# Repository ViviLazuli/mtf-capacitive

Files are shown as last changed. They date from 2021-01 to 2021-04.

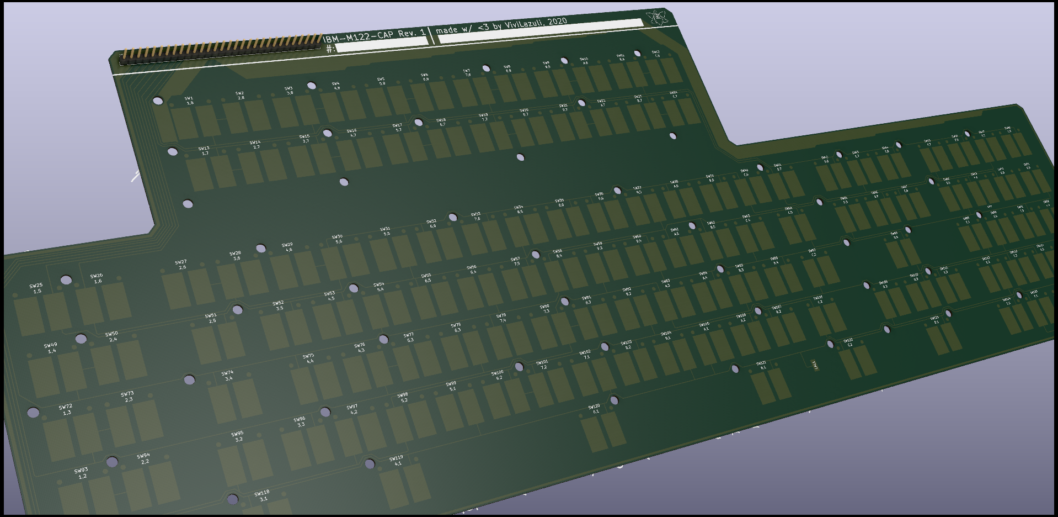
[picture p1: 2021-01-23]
docs/render-front.png

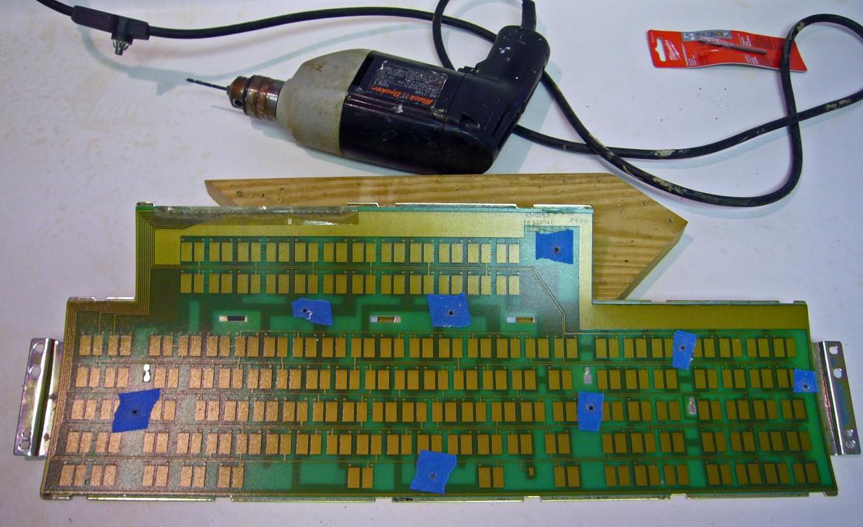
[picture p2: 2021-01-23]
docs/reverse-engineering/2.png

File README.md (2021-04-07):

# MtF122 Capacitive Conversion PCB for IBM Model M 122-key Keyboards

### Rev. 2 / Rev. B

This version is in prototyping phase. However, it does function.

It has only been tested with a late thin-bezeled variant of the M122. The screw holes have a tight fit and may require widening and more clearance around them for traces.
!The screw holes may not be in the correct positions for other M122 variants!

Capacitive pad measurements are taken from i$/idollar's FSSK and FEXT PCB designs, which I believe are directly measured from the original Model F PCBs.

The PCB thickness should be 0.6mm. This is thin enough to allow the board to flex into shape without preforming it with heat and duct tape (which I couldn't make work anyway).

Standard glossy soldermask is probably the best choice. JLCPCB has had issues with wear on their black soldermask before. They have changed the formula, but a standard green/red/blue/yellow/purple/white/etc. glossy solder mask is probaby the safest bet for keyswitch wear resistance.
Higher wear resistance might also be achieved by coating the front of the capacitive pads in silkscreen, as silkscreen is an extra layer of epoxy. I am unsure how this will affect keyfeel or actuation, however.

There is a bullseye circle on the front of the board. This is for drilling a hole for a trackpoint module. There are redundant traces to allow for safer drilling at this location, but this functionality has not been tested!

The diameter of the copper around the connecting pads could be to be enlarged. They are too fragile and I had one rip out when disconnecting a mill-max pin header connector (fortunately it was just a redundant ground).

For connecting the board to an xwhatsit or other controller, I would recommend 3M 8132/06 100, which has the correct pitch for this board and xwhatsit:
https://www.digikey.com/en/products/detail/3m/8132-06-100/7809902

The key matrix of the PCB is reverse-engineered from photos of original F122 PCBs and should be exactly the same. The connector is likely in a slightly different position though.

The screw hole placement was prototyped with paper by printing an SVG output of the board edge cuts and drill holes on multiple sheets of paper, pasting them together, cutting out the paper 'PCB', and hole punching the drill hole locations. A few iterations of this paper prototyping method allowed me to test hole locations and board fitment against the barrel plate without having to make an entire PCB first.

I did not clad the steel backplate in tape before mounting the PCB. The solder mask should provide adequate isolation. Just make sure the steel is clean and there are no burrs/jagged edges that could scrape the PCB.

Please read LICENSE.txt for the full MIT License.

Some photos are here for reverse-engineering reference only and are not mine nor included under the license.

| Authors |
|-|
| ViviLazuli |
| Razerban |

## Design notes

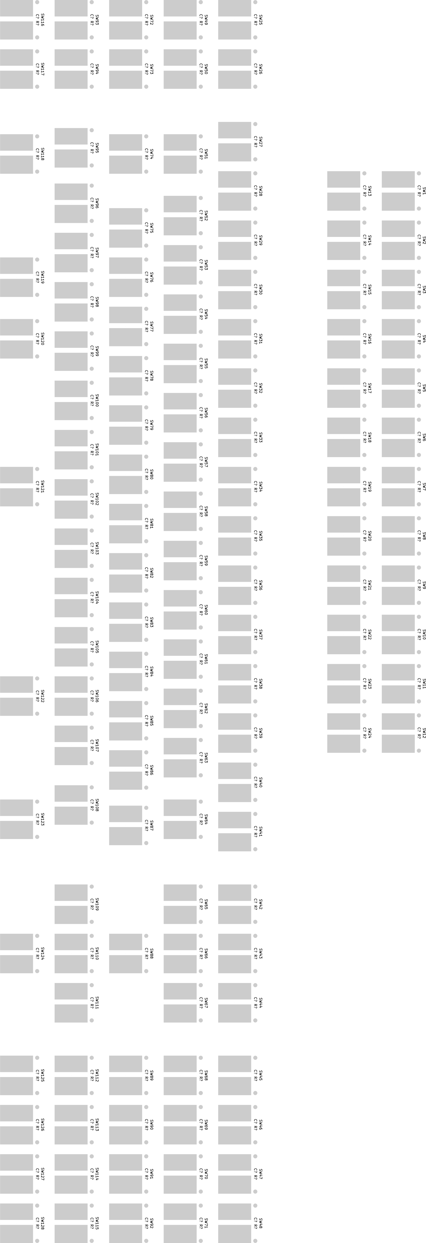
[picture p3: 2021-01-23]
docs/tmp/f122-brd-front.svg.png

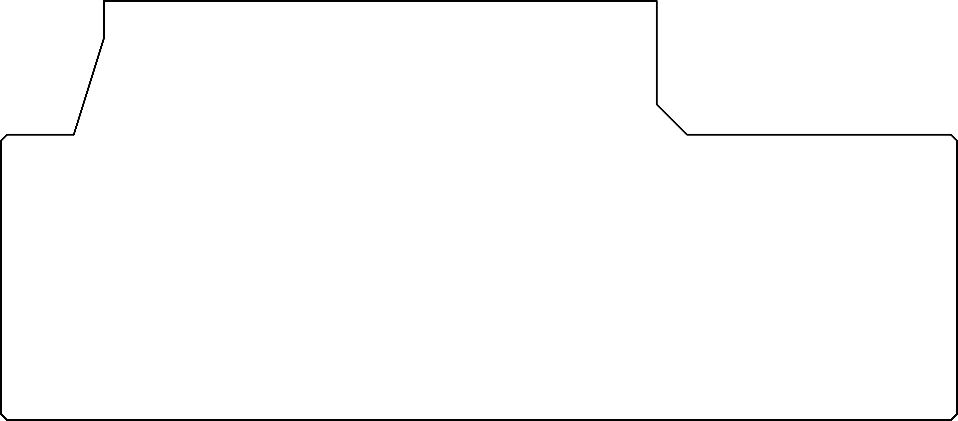
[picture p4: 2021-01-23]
docs/tmp/edge-cuts.png

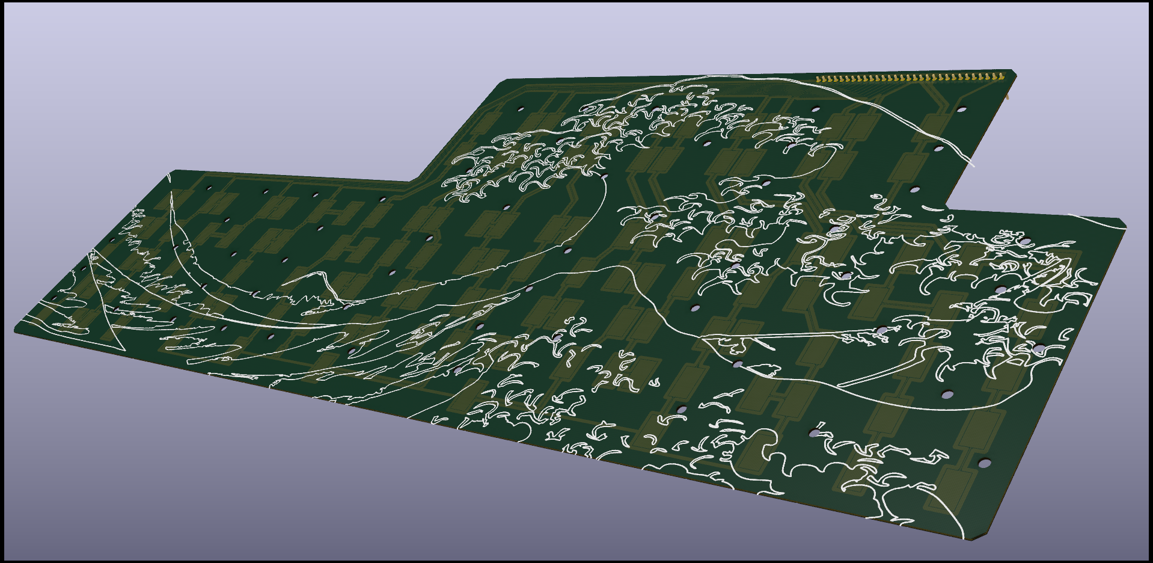
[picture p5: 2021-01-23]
docs/render back.png

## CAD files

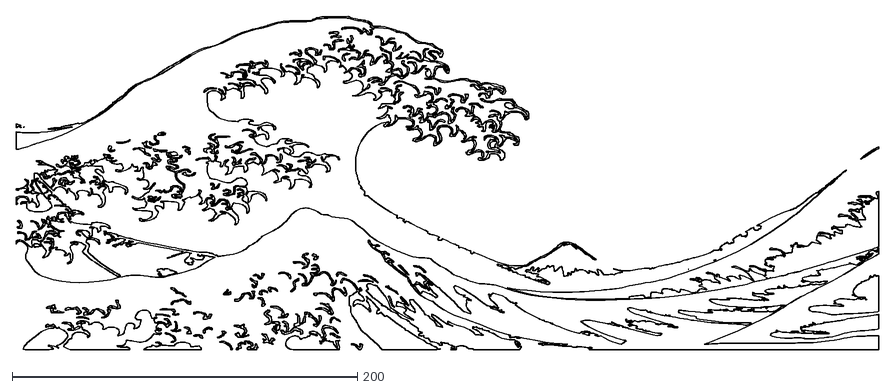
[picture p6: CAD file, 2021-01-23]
docs/art/wave.dxf
500.0 x 193.0

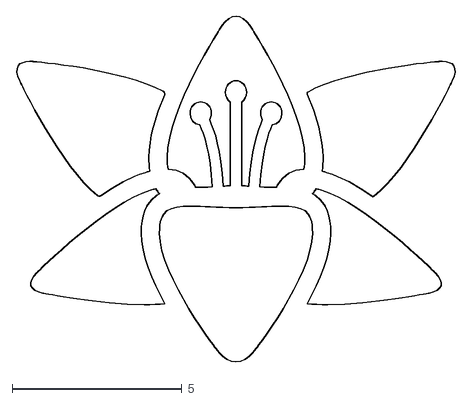
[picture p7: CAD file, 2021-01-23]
docs/art/lily.dxf
13.0 x 10.2

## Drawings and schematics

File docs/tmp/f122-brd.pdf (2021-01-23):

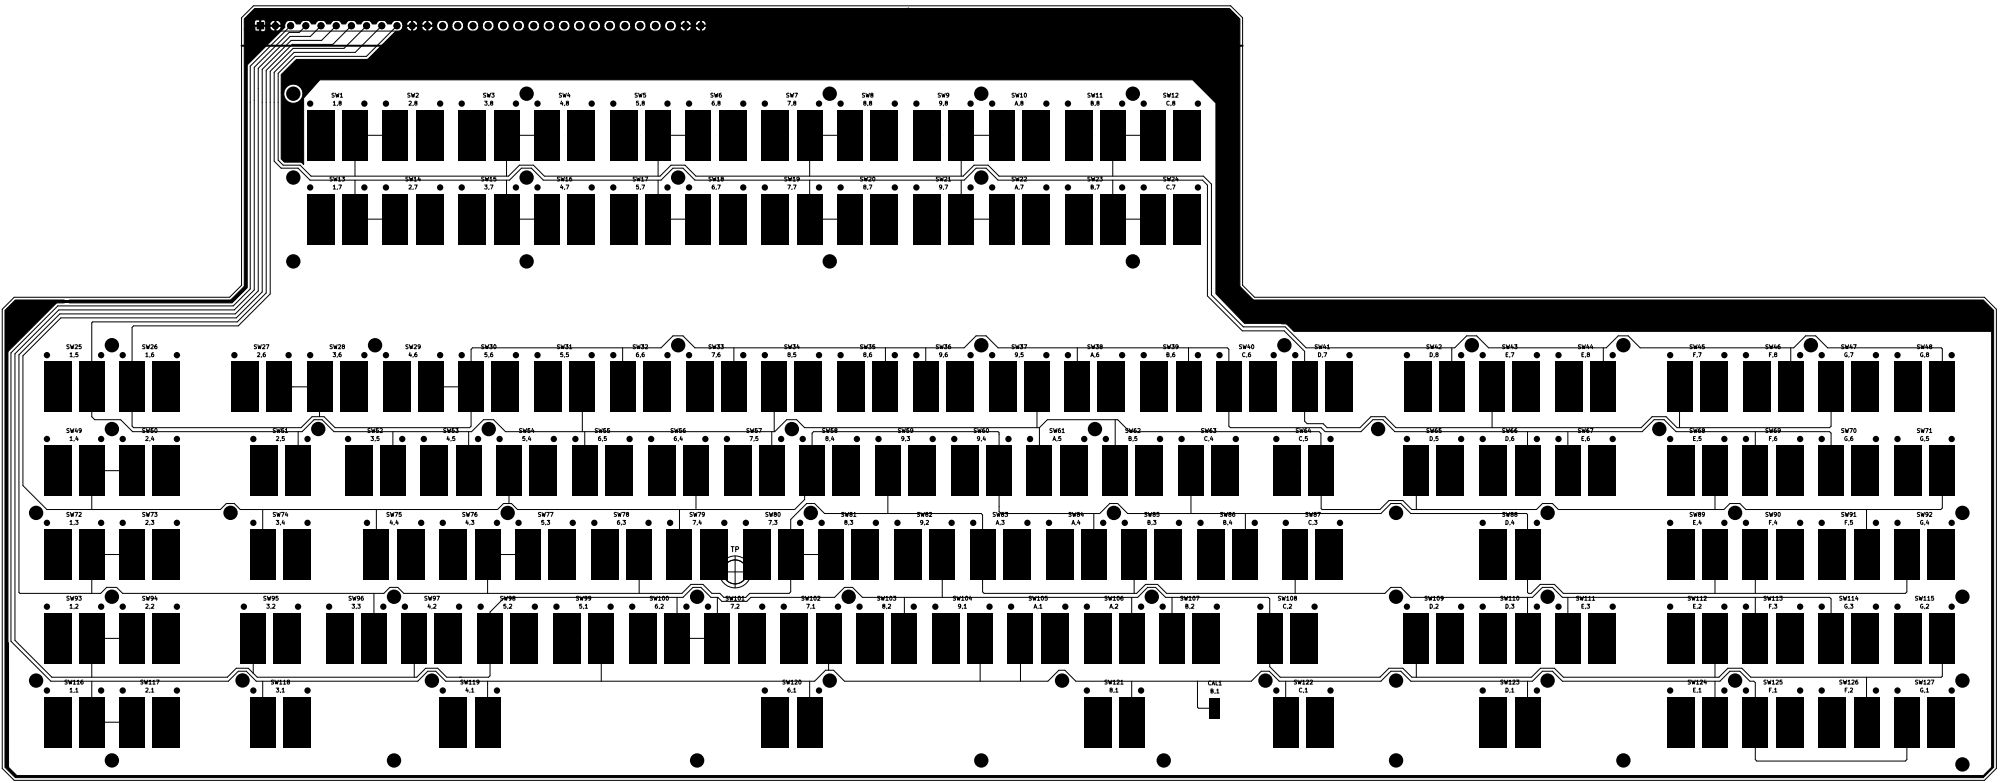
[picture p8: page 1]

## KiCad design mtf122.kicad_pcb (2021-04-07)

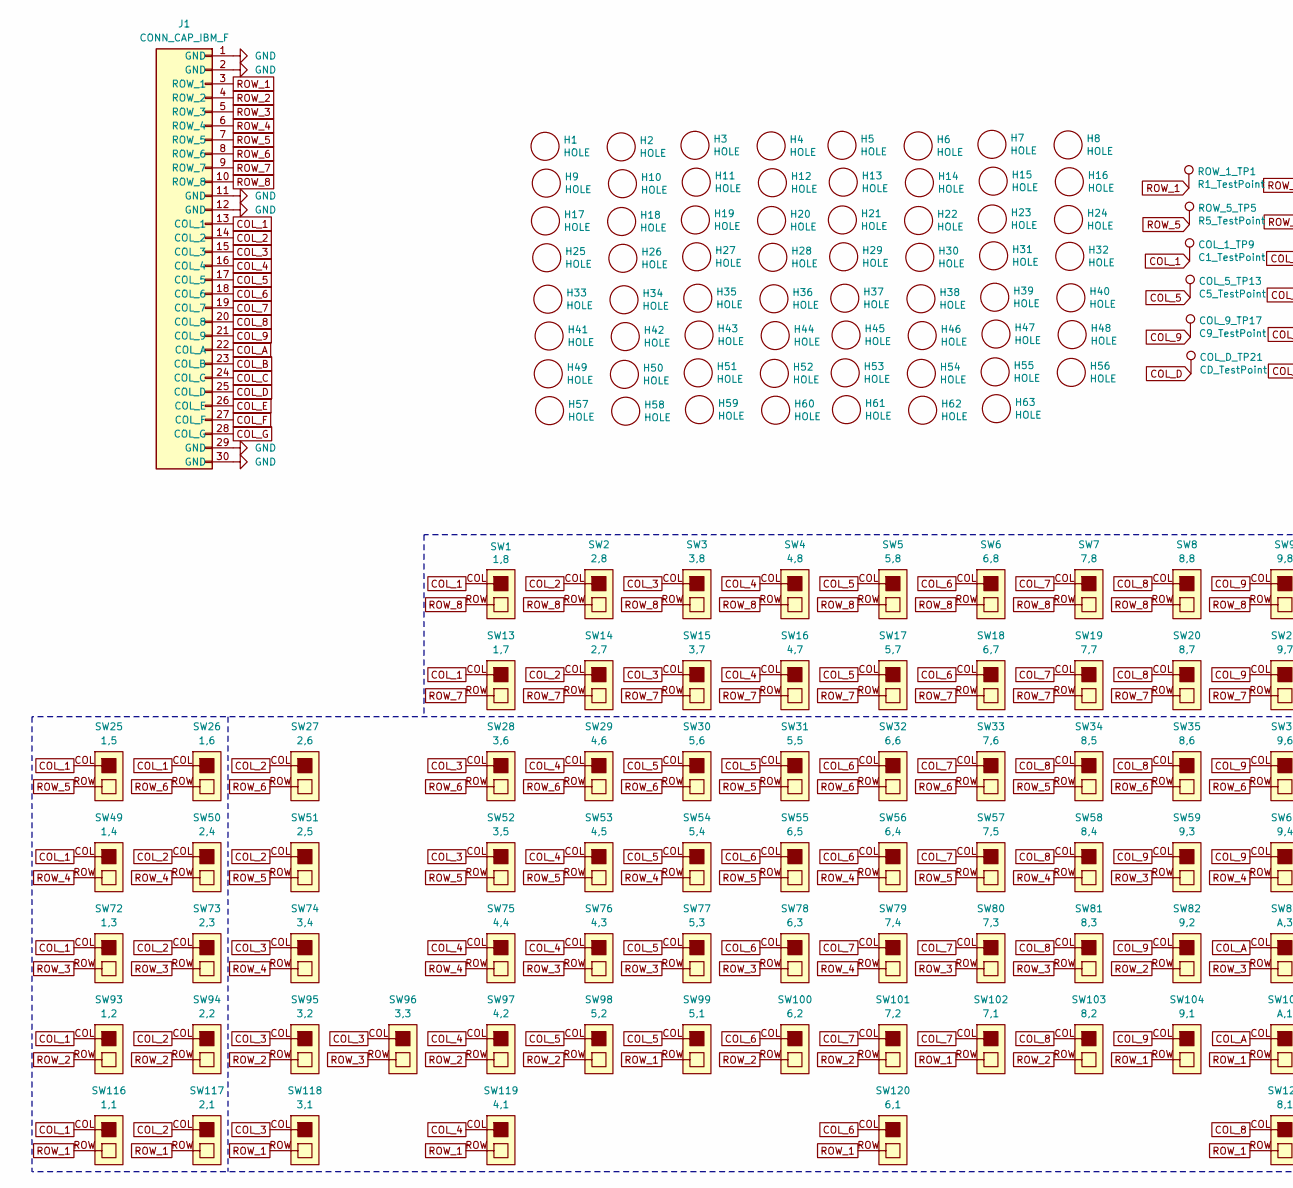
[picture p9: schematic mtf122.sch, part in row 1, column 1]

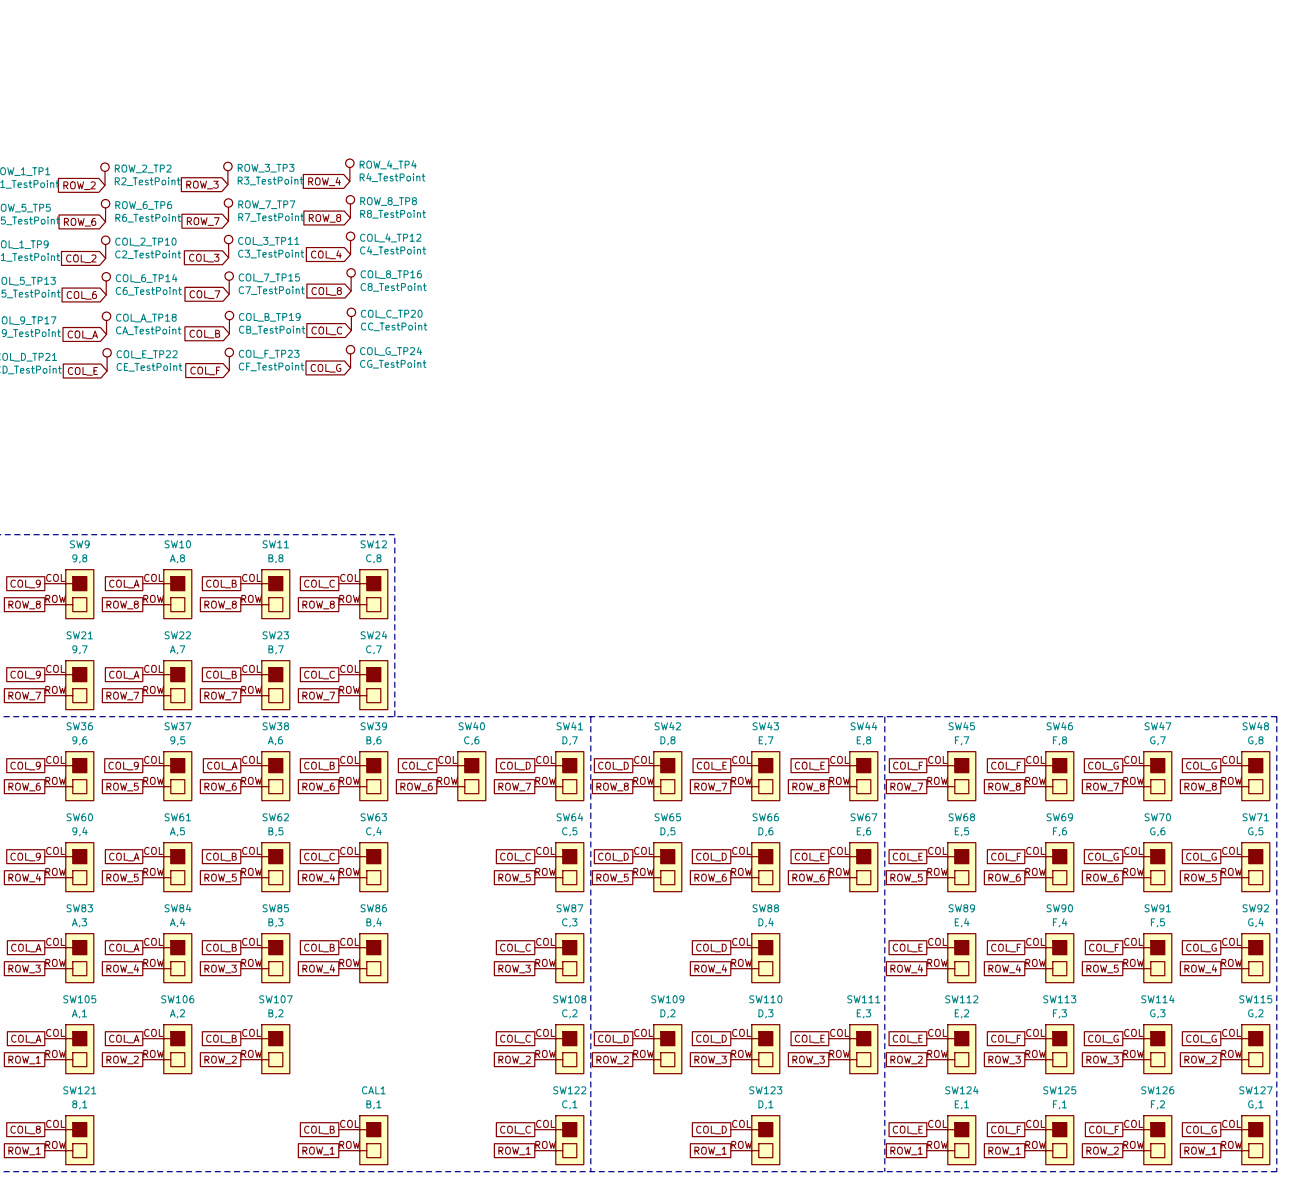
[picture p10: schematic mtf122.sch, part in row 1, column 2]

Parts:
CAL1: B,1; CAL_CAP_IBM_F
COL_1_TP9: C1_TestPoint; TestPoint_Pad_D1.0mm
COL_2_TP10: C2_TestPoint; TestPoint_Pad_D1.0mm
COL_3_TP11: C3_TestPoint; TestPoint_Pad_D1.0mm
COL_4_TP12: C4_TestPoint; TestPoint_Pad_D1.0mm
COL_5_TP13: C5_TestPoint; TestPoint_Pad_D1.0mm
COL_6_TP14: C6_TestPoint; TestPoint_Pad_D1.0mm
COL_7_TP15: C7_TestPoint; TestPoint_Pad_D1.0mm
COL_8_TP16: C8_TestPoint; TestPoint_Pad_D1.0mm
COL_9_TP17: C9_TestPoint; TestPoint_Pad_D1.0mm
COL_A_TP18: CA_TestPoint; TestPoint_Pad_D1.0mm
COL_B_TP19: CB_TestPoint; TestPoint_Pad_D1.0mm
COL_C_TP20: CC_TestPoint; TestPoint_Pad_D1.0mm
COL_D_TP21: CD_TestPoint; TestPoint_Pad_D1.0mm
COL_E_TP22: CE_TestPoint; TestPoint_Pad_D1.0mm
COL_F_TP23: CF_TestPoint; TestPoint_Pad_D1.0mm
COL_G_TP24: CG_TestPoint; TestPoint_Pad_D1.0mm
H1, H2, H3, H4, H5, H6, H7, H8, H9, H10, H11, H12, H13, H14, H15, H16, H17, H18, H19, H20, H21, H22, H23, H24, H25, H26, H27, H28, H29, H30, H31, H32, H33, H34, H35, H36, H37, H38, H39, H40, H41, H42, H43, H44, H45, H46, H47, H48, H49, H50, H51, H52, H53, H54, H55, H56, H57, H58, H59, H60, H61, H62, H63: HOLE
J1: CONN_CAP_IBM_F
ROW_1_TP1: R1_TestPoint; TestPoint_Pad_D1.0mm
ROW_2_TP2: R2_TestPoint; TestPoint_Pad_D1.0mm
ROW_3_TP3: R3_TestPoint; TestPoint_Pad_D1.0mm
ROW_4_TP4: R4_TestPoint; TestPoint_Pad_D1.0mm
ROW_5_TP5: R5_TestPoint; TestPoint_Pad_D1.0mm
ROW_6_TP6: R6_TestPoint; TestPoint_Pad_D1.0mm
ROW_7_TP7: R7_TestPoint; TestPoint_Pad_D1.0mm
ROW_8_TP8: R8_TestPoint; TestPoint_Pad_D1.0mm
SW1: 1,8; SW_CAP_IBM_F_ALT
SW2: 2,8; SW_CAP_IBM_F
SW3: 3,8; SW_CAP_IBM_F_ALT
SW4: 4,8; SW_CAP_IBM_F
SW5: 5,8; SW_CAP_IBM_F_ALT
SW6: 6,8; SW_CAP_IBM_F
SW7: 7,8; SW_CAP_IBM_F_ALT
SW8: 8,8; SW_CAP_IBM_F
SW9: 9,8; SW_CAP_IBM_F_ALT
SW10: A,8; SW_CAP_IBM_F
SW11: B,8; SW_CAP_IBM_F_ALT
SW12: C,8; SW_CAP_IBM_F
SW13: 1,7; SW_CAP_IBM_F_ALT
SW14: 2,7; SW_CAP_IBM_F
SW15: 3,7; SW_CAP_IBM_F_ALT
SW16: 4,7; SW_CAP_IBM_F
SW17: 5,7; SW_CAP_IBM_F_ALT
SW18: 6,7; SW_CAP_IBM_F
SW19: 7,7; SW_CAP_IBM_F_ALT
SW20: 8,7; SW_CAP_IBM_F
SW21: 9,7; SW_CAP_IBM_F_ALT
SW22: A,7; SW_CAP_IBM_F
SW23: B,7; SW_CAP_IBM_F_ALT
SW24: C,7; SW_CAP_IBM_F
SW25: 1,5; SW_CAP_IBM_F_ALT
SW26: 1,6; SW_CAP_IBM_F
SW27: 2,6; SW_CAP_IBM_F_ALT
SW28: 3,6; SW_CAP_IBM_F
SW29: 4,6; SW_CAP_IBM_F_ALT
SW30: 5,6; SW_CAP_IBM_F
SW31: 5,5; SW_CAP_IBM_F_ALT
SW32: 6,6; SW_CAP_IBM_F
SW33: 7,6; SW_CAP_IBM_F_ALT
SW34: 8,5; SW_CAP_IBM_F
SW35: 8,6; SW_CAP_IBM_F_ALT
SW36: 9,6; SW_CAP_IBM_F
SW37: 9,5; SW_CAP_IBM_F_ALT
SW38: A,6; SW_CAP_IBM_F
SW39: B,6; SW_CAP_IBM_F_ALT
SW40: C,6; SW_CAP_IBM_F
SW41: D,7; SW_CAP_IBM_F
SW42: D,8; SW_CAP_IBM_F_ALT
SW43: E,7; SW_CAP_IBM_F
SW44: E,8; SW_CAP_IBM_F_ALT
SW45: F,7; SW_CAP_IBM_F
SW46: F,8; SW_CAP_IBM_F_ALT
SW47: G,7; SW_CAP_IBM_F
SW48: G,8; SW_CAP_IBM_F_ALT
SW49: 1,4; SW_CAP_IBM_F_ALT
SW50: 2,4; SW_CAP_IBM_F
SW51: 2,5; SW_CAP_IBM_F_ALT
SW52: 3,5; SW_CAP_IBM_F_ALT
SW53: 4,5; SW_CAP_IBM_F_ALT
SW54: 5,4; SW_CAP_IBM_F
SW55: 6,5; SW_CAP_IBM_F
SW56: 6,4; SW_CAP_IBM_F_ALT
SW57: 7,5; SW_CAP_IBM_F_ALT
SW58: 8,4; SW_CAP_IBM_F
SW59: 9,3; SW_CAP_IBM_F
SW60: 9,4; SW_CAP_IBM_F_ALT
SW61: A,5; SW_CAP_IBM_F
SW62: B,5; SW_CAP_IBM_F
SW63: C,4; SW_CAP_IBM_F
SW64: C,5; SW_CAP_IBM_F_ALT
SW65: D,5; SW_CAP_IBM_F
SW66: D,6; SW_CAP_IBM_F_ALT
SW67: E,6; SW_CAP_IBM_F
SW68: E,5; SW_CAP_IBM_F_ALT
SW69: F,6; SW_CAP_IBM_F
SW70: G,6; SW_CAP_IBM_F
SW71: G,5; SW_CAP_IBM_F_ALT
SW72: 1,3; SW_CAP_IBM_F_ALT
SW73: 2,3; SW_CAP_IBM_F
SW74: 3,4; SW_CAP_IBM_F
SW75: 4,4; SW_CAP_IBM_F
SW76: 4,3; SW_CAP_IBM_F_ALT
SW77: 5,3; SW_CAP_IBM_F
SW78: 6,3; SW_CAP_IBM_F_ALT
SW79: 7,4; SW_CAP_IBM_F
SW80: 7,3; SW_CAP_IBM_F_ALT
SW81: 8,3; SW_CAP_IBM_F
SW82: 9,2; SW_CAP_IBM_F_ALT
SW83: A,3; SW_CAP_IBM_F
SW84: A,4; SW_CAP_IBM_F_ALT
SW85: B,3; SW_CAP_IBM_F
SW86: B,4; SW_CAP_IBM_F_ALT
SW87: C,3; SW_CAP_IBM_F
SW88: D,4; SW_CAP_IBM_F_ALT
SW89: E,4; SW_CAP_IBM_F_ALT
SW90: F,4; SW_CAP_IBM_F
SW91: F,5; SW_CAP_IBM_F_ALT
SW92: G,4; SW_CAP_IBM_F
SW93: 1,2; SW_CAP_IBM_F_ALT
SW94: 2,2; SW_CAP_IBM_F
SW95: 3,2; SW_CAP_IBM_F
SW96: 3,3; SW_CAP_IBM_F_ALT
SW97: 4,2; SW_CAP_IBM_F
SW98: 5,2; SW_CAP_IBM_F
SW99: 5,1; SW_CAP_IBM_F_ALT
SW100: 6,2; SW_CAP_IBM_F_ALT
SW101: 7,2; SW_CAP_IBM_F
SW102: 7,1; SW_CAP_IBM_F_ALT
SW103: 8,2; SW_CAP_IBM_F_ALT
SW104: 9,1; SW_CAP_IBM_F_ALT
SW105: A,1; SW_CAP_IBM_F
SW106: A,2; SW_CAP_IBM_F_ALT
SW107: B,2; SW_CAP_IBM_F
SW108: C,2; SW_CAP_IBM_F
SW109: D,2; SW_CAP_IBM_F
SW110: D,3; SW_CAP_IBM_F_ALT
SW111: E,3; SW_CAP_IBM_F
SW112: E,2; SW_CAP_IBM_F_ALT
SW113: F,3; SW_CAP_IBM_F
SW114: G,3; SW_CAP_IBM_F
SW115: G,2; SW_CAP_IBM_F_ALT
SW116: 1,1; SW_CAP_IBM_F_ALT
SW117: 2,1; SW_CAP_IBM_F
SW118: 3,1; SW_CAP_IBM_F
SW119: 4,1; SW_CAP_IBM_F_ALT
SW120: 6,1; SW_CAP_IBM_F_ALT
SW121: 8,1; SW_CAP_IBM_F_ALT
SW122: C,1; SW_CAP_IBM_F
SW123: D,1; SW_CAP_IBM_F_ALT
SW124: E,1; SW_CAP_IBM_F_ALT
SW125: F,1; SW_CAP_IBM_F
SW126: F,2; SW_CAP_IBM_F_ALT
SW127: G,1; SW_CAP_IBM_F

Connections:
COL_1: COL_1_TP9.1, J1.13 (COL_1), SW1.COL, SW13.COL, SW25.COL, SW26.COL, SW49.COL, SW72.COL, SW93.COL, SW116.COL
COL_2: COL_2_TP10.1, J1.14 (COL_2), SW2.COL, SW14.COL, SW27.COL, SW50.COL, SW51.COL, SW73.COL, SW94.COL, SW117.COL
COL_3: COL_3_TP11.1, J1.15 (COL_3), SW3.COL, SW15.COL, SW28.COL, SW52.COL, SW74.COL, SW95.COL, SW96.COL, SW118.COL
COL_4: COL_4_TP12.1, J1.16 (COL_4), SW4.COL, SW16.COL, SW29.COL, SW53.COL, SW75.COL, SW76.COL, SW97.COL, SW119.COL
COL_5: COL_5_TP13.1, J1.17 (COL_5), SW5.COL, SW17.COL, SW30.COL, SW31.COL, SW54.COL, SW77.COL, SW98.COL, SW99.COL
COL_6: COL_6_TP14.1, J1.18 (COL_6), SW6.COL, SW18.COL, SW32.COL, SW55.COL, SW56.COL, SW78.COL, SW100.COL, SW120.COL
COL_7: COL_7_TP15.1, J1.19 (COL_7), SW7.COL, SW19.COL, SW33.COL, SW57.COL, SW79.COL, SW80.COL, SW101.COL, SW102.COL
COL_8: COL_8_TP16.1, J1.20 (COL_8), SW8.COL, SW20.COL, SW34.COL, SW35.COL, SW58.COL, SW81.COL, SW103.COL, SW121.COL
COL_9: COL_9_TP17.1, J1.21 (COL_9), SW9.COL, SW21.COL, SW36.COL, SW37.COL, SW59.COL, SW60.COL, SW82.COL, SW104.COL
COL_A: COL_A_TP18.1, J1.22 (COL_A), SW10.COL, SW22.COL, SW38.COL, SW61.COL, SW83.COL, SW84.COL, SW105.COL, SW106.COL
COL_B: CAL1.COL, COL_B_TP19.1, J1.23 (COL_B), SW11.COL, SW23.COL, SW39.COL, SW62.COL, SW85.COL, SW86.COL, SW107.COL
COL_C: COL_C_TP20.1, J1.24 (COL_C), SW12.COL, SW24.COL, SW40.COL, SW63.COL, SW64.COL, SW87.COL, SW108.COL, SW122.COL
COL_D: COL_D_TP21.1, J1.25 (COL_D), SW41.COL, SW42.COL, SW65.COL, SW66.COL, SW88.COL, SW109.COL, SW110.COL, SW123.COL
COL_E: COL_E_TP22.1, J1.26 (COL_E), SW43.COL, SW44.COL, SW67.COL, SW68.COL, SW89.COL, SW111.COL, SW112.COL, SW124.COL
COL_F: COL_F_TP23.1, J1.27 (COL_F), SW45.COL, SW46.COL, SW69.COL, SW90.COL, SW91.COL, SW113.COL, SW125.COL, SW126.COL
COL_G: COL_G_TP24.1, J1.28 (COL_G), SW47.COL, SW48.COL, SW70.COL, SW71.COL, SW92.COL, SW114.COL, SW115.COL, SW127.COL
GND: J1.1 (GND), J1.2 (GND), J1.11 (GND), J1.12 (GND), J1.29 (GND), J1.30 (GND)
ROW_1: CAL1.ROW, J1.3 (ROW_1), ROW_1_TP1.1, SW99.ROW, SW102.ROW, SW104.ROW, SW105.ROW, SW116.ROW, SW117.ROW, SW118.ROW, SW119.ROW, SW120.ROW, SW121.ROW, SW122.ROW, SW123.ROW, SW124.ROW, SW125.ROW, SW127.ROW
ROW_2: J1.4 (ROW_2), ROW_2_TP2.1, SW82.ROW, SW93.ROW, SW94.ROW, SW95.ROW, SW97.ROW, SW98.ROW, SW100.ROW, SW101.ROW, SW103.ROW, SW106.ROW, SW107.ROW, SW108.ROW, SW109.ROW, SW112.ROW, SW115.ROW, SW126.ROW
ROW_3: J1.5 (ROW_3), ROW_3_TP3.1, SW59.ROW, SW72.ROW, SW73.ROW, SW76.ROW, SW77.ROW, SW78.ROW, SW80.ROW, SW81.ROW, SW83.ROW, SW85.ROW, SW87.ROW, SW96.ROW, SW110.ROW, SW111.ROW, SW113.ROW, SW114.ROW
ROW_4: J1.6 (ROW_4), ROW_4_TP4.1, SW49.ROW, SW50.ROW, SW54.ROW, SW56.ROW, SW58.ROW, SW60.ROW, SW63.ROW, SW74.ROW, SW75.ROW, SW79.ROW, SW84.ROW, SW86.ROW, SW88.ROW, SW89.ROW, SW90.ROW, SW92.ROW
ROW_5: J1.7 (ROW_5), ROW_5_TP5.1, SW25.ROW, SW31.ROW, SW34.ROW, SW37.ROW, SW51.ROW, SW52.ROW, SW53.ROW, SW55.ROW, SW57.ROW, SW61.ROW, SW62.ROW, SW64.ROW, SW65.ROW, SW68.ROW, SW71.ROW, SW91.ROW
ROW_6: J1.8 (ROW_6), ROW_6_TP6.1, SW26.ROW, SW27.ROW, SW28.ROW, SW29.ROW, SW30.ROW, SW32.ROW, SW33.ROW, SW35.ROW, SW36.ROW, SW38.ROW, SW39.ROW, SW40.ROW, SW66.ROW, SW67.ROW, SW69.ROW, SW70.ROW
ROW_7: J1.9 (ROW_7), ROW_7_TP7.1, SW13.ROW, SW14.ROW, SW15.ROW, SW16.ROW, SW17.ROW, SW18.ROW, SW19.ROW, SW20.ROW, SW21.ROW, SW22.ROW, SW23.ROW, SW24.ROW, SW41.ROW, SW43.ROW, SW45.ROW, SW47.ROW
ROW_8: J1.10 (ROW_8), ROW_8_TP8.1, SW1.ROW, SW2.ROW, SW3.ROW, SW4.ROW, SW5.ROW, SW6.ROW, SW7.ROW, SW8.ROW, SW9.ROW, SW10.ROW, SW11.ROW, SW12.ROW, SW42.ROW, SW44.ROW, SW46.ROW, SW48.ROW

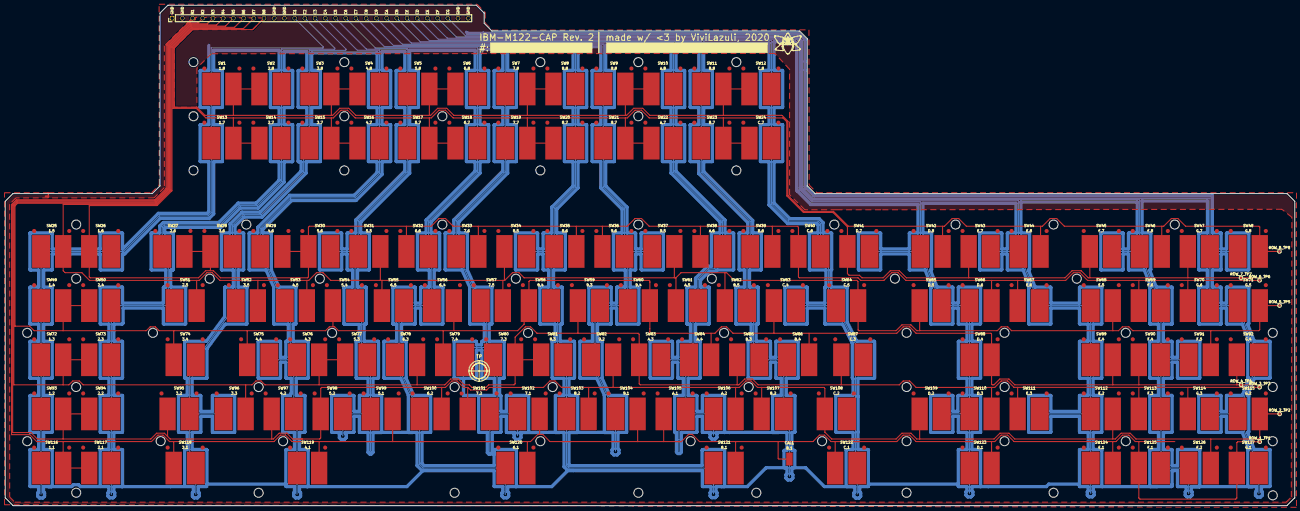
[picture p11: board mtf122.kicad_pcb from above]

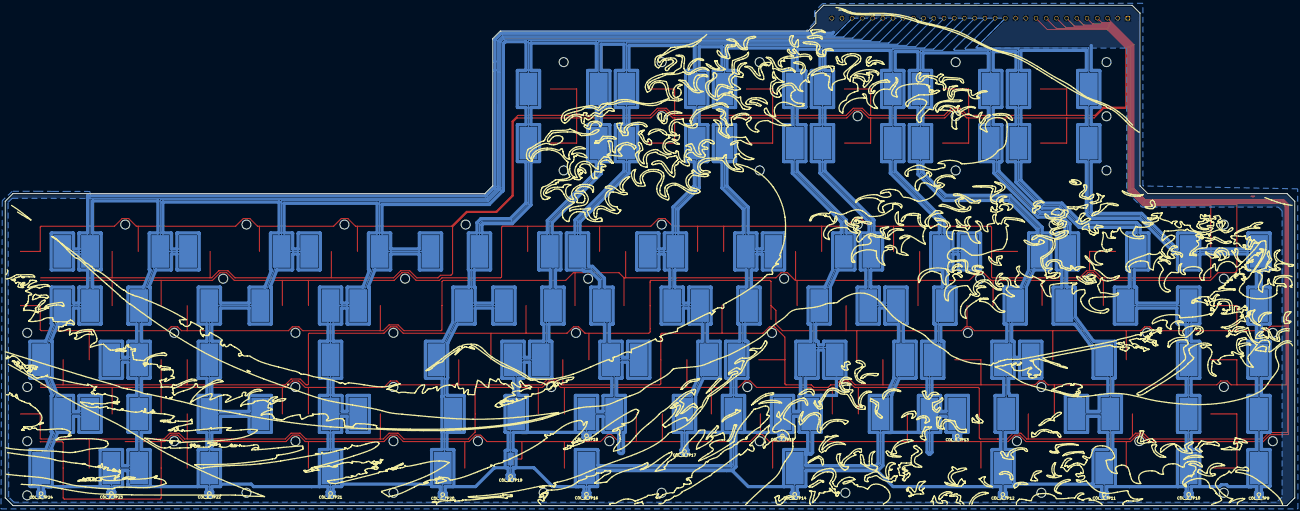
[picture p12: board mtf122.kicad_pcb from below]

Board: 2 copper layers, 500.0 x 194.0 mm, 216 parts (16 on the bottom side), 25 nets.

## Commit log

2021-01-23 initial publishing - VERY WIP
    [f122-B_Cu.gbr, f122-B_Mask.gbr, f122-B_SilkS.gbr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]
2021-02-01 Update CONN_CAP_IBM_F footprint
    [mtf122.kicad_pcb]
2021-02-01 Updated SW_CAP_IBM_F and SW_CAP_IBM_F_ALT footprints
    [mtf122.kicad_pcb]
2021-02-01 Added extra appendages to be compliant with IBM rules
    [mtf122.kicad_pcb]
2021-02-01 Added test points for testing continuity on ROWS
    [mtf122.kicad_pcb]
2021-02-01 Added test points for testing continuity on COLUMNS
    [mtf122.kicad_pcb]
2021-02-01 1- Resized the top edge of the PCB to fit inside the keyboard without any permanent irreversable modification. 2- Routed the connections to take less space 3- Added a GND fill zone on the back of the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
    [mtf122.kicad_pcb]
2021-02-01 Some cleaning
    [mtf122.kicad_pcb]
2021-02-01 Removed column test points from F.SilkS
    [mtf122.kicad_pcb]
2021-02-25 Cleanup and schematic update
    [f122-B_Cu.gbr, f122-B_Mask.gbr, f122-F_Cu.gbr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]
